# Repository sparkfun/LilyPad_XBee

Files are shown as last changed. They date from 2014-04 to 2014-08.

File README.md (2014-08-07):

LilyPad XBee
============

[LilyPad XBee
*LilyPad XBee (DEV-08937)*](https://www.sparkfun.com/products/8937)

The LilyPad Xbee is a breakout board for the popular XBee modules. 
Board includes easy-to-sew tabs and all the necessary power regulation to run on the LilyPad system. 

Repository Contents
-------------------

* **/Hardware** - All Eagle design files (.brd, .sch, .STL)
* **/Production** - Test bed files and production panel files

License Information
-------------------
The hardware is released under [Creative Commons ShareAlike 4.0 International](https://creativecommons.org/licenses/by-sa/4.0/).

Distributed as-is; no warranty is given.

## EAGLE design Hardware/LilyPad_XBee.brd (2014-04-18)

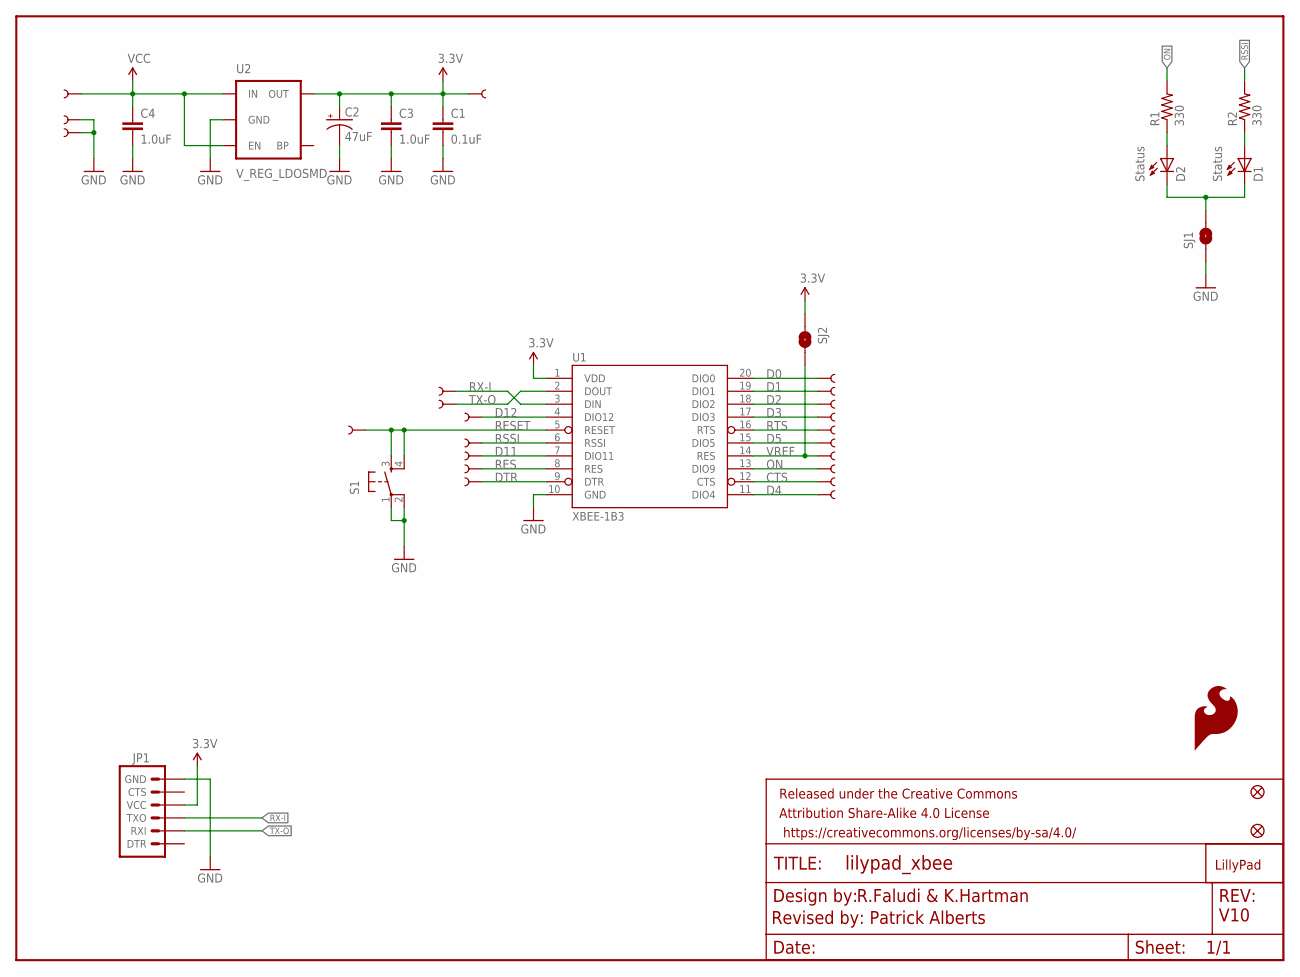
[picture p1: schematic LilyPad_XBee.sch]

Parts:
C1: 0.1uF; 0603-CAP
C2: 47uF; EIA3528
C3, C4: 1.0uF; 0603-CAP
D1, D2: Status; LED-0603
FID1, FID2: FIDUCIAL1X2; FIDUCIAL-1X2
FRAME1: FRAME-LETTER; CREATIVE_COMMONS
GND: SEWTAP9; PETAL-LONG-1-2SIDE
JP1: ARDUINO_SERIAL_PROGRAMPTH; 1X06
LOGO1: SFE_LOGO_FLAME.1COP; SFE_LOGO_FLAME_COPPER_.1
R1, R2: 330; 0603-RES
S1: TAC_SWITCHSMD; TACTILE_SWITCH_SMD
SJ1, SJ2: SOLDERJUMPERNC2; SJ_2S-NOTRACE
U1: XBEE-1B3; XBEE-SMD
U2: V_REG_LDOSMD; SOT23-5
U$1: LOGO-LPLP; LOGO-LILYPAD
U$4, U$30, U$31, U$32, U$33, U$34, U$35, U$36, U$37, U$38, U$39, U$40, U$41, U$42, U$43, U$44, U$45, U$46, U$47, U$48, U$51: SEWTAP9; PETAL-LONG-1-2SIDE

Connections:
3.3V: C1.1, C2.A (+), C3.1, JP1.4 (VCC), SJ2.1, U1.1 (VDD), U2.5 (OUT), U$47.1
CTS: U1.12 (CTS), U$38.1
D0: U1.20 (DIO0), U$34.1
D1: U1.19 (DIO1), U$33.1
D2: U1.18 (DIO2), U$32.1
D3: U1.17 (DIO3), U$31.1
D4: U1.11 (DIO4), U$37.1
D5: U1.15 (DIO5), U$4.1
D11: U1.7 (DIO11), U$42.1
D12: U1.4 (DIO12), U$43.1
DTR: U1.9 (DTR), U$48.1
GND: C1.2, C2.C (-), C3.2, C4.2, JP1.6 (GND), S1.1, S1.2, SJ1.1, U1.10 (GND), U2.2 (GND), U$36.1, U$46.1
unnamed: D1.A, R2.1
unnamed: D2.A, R1.1
unnamed: D1.C, D2.C, SJ1.2
ON: R1.2, U1.13 (DIO9), U$39.1
RES: U1.8 (RES), U$41.1
RESET: GND.1, S1.3, S1.4, U1.5 (RESET)
RSSI: R2.2, U1.6 (RSSI), U$51.1
RTS: U1.16 (RTS), U$30.1
RX-I: JP1.3 (TXO), U1.3 (DIN), U$45.1
TX-O: JP1.2 (RXI), U1.2 (DOUT), U$44.1
VCC: C4.1, U2.1 (IN), U2.3 (EN), U$35.1
VREF: SJ2.2, U1.14 (RES), U$40.1

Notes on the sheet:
R.Faludi & K.Hartman
Revised by: Patrick Alberts
V10

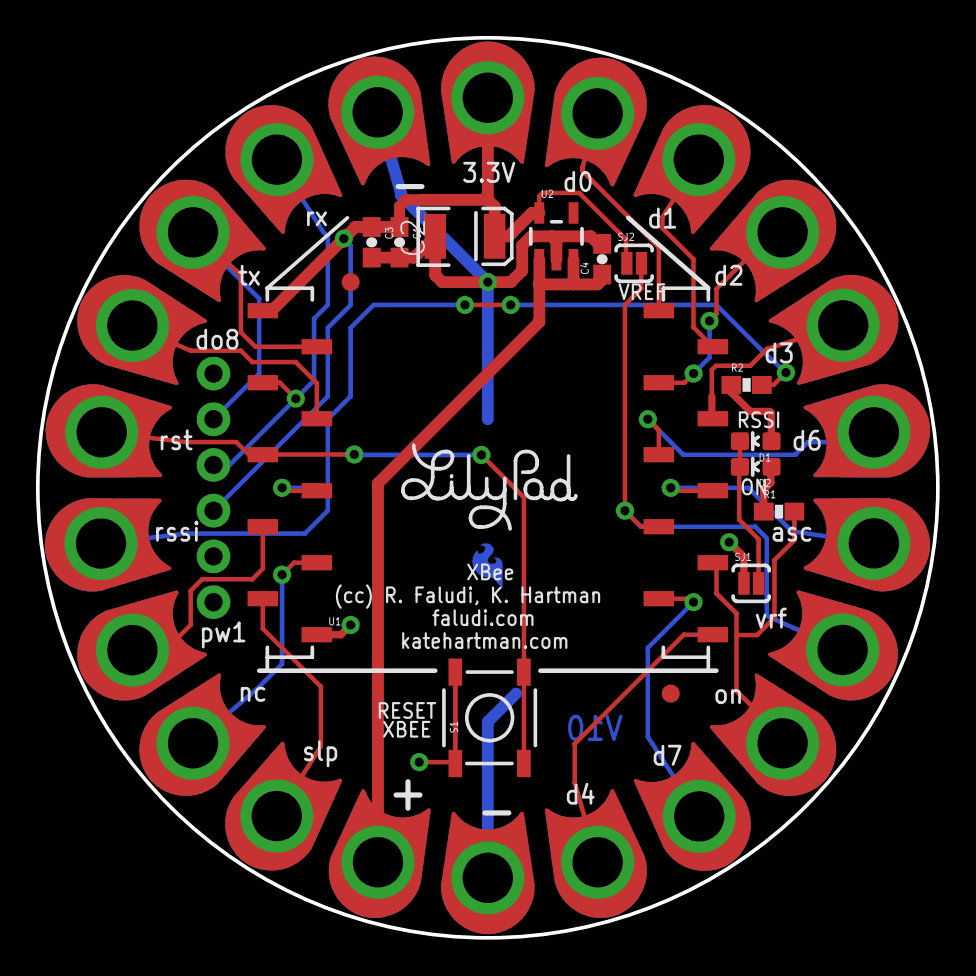
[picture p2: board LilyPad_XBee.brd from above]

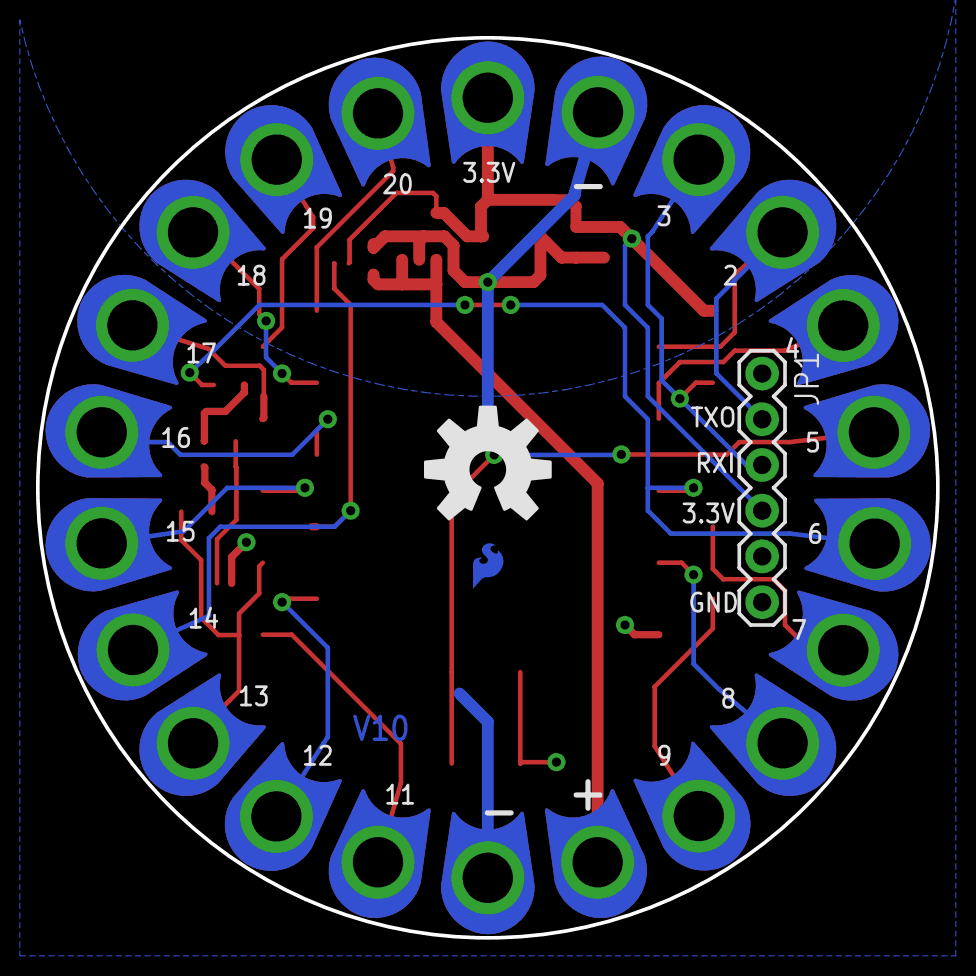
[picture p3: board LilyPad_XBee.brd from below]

Board: 2 copper layers, 50.0 x 50.0 mm, 42 parts (3 on the bottom side), 24 nets.

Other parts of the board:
U$2: OSHW-LOGO-L

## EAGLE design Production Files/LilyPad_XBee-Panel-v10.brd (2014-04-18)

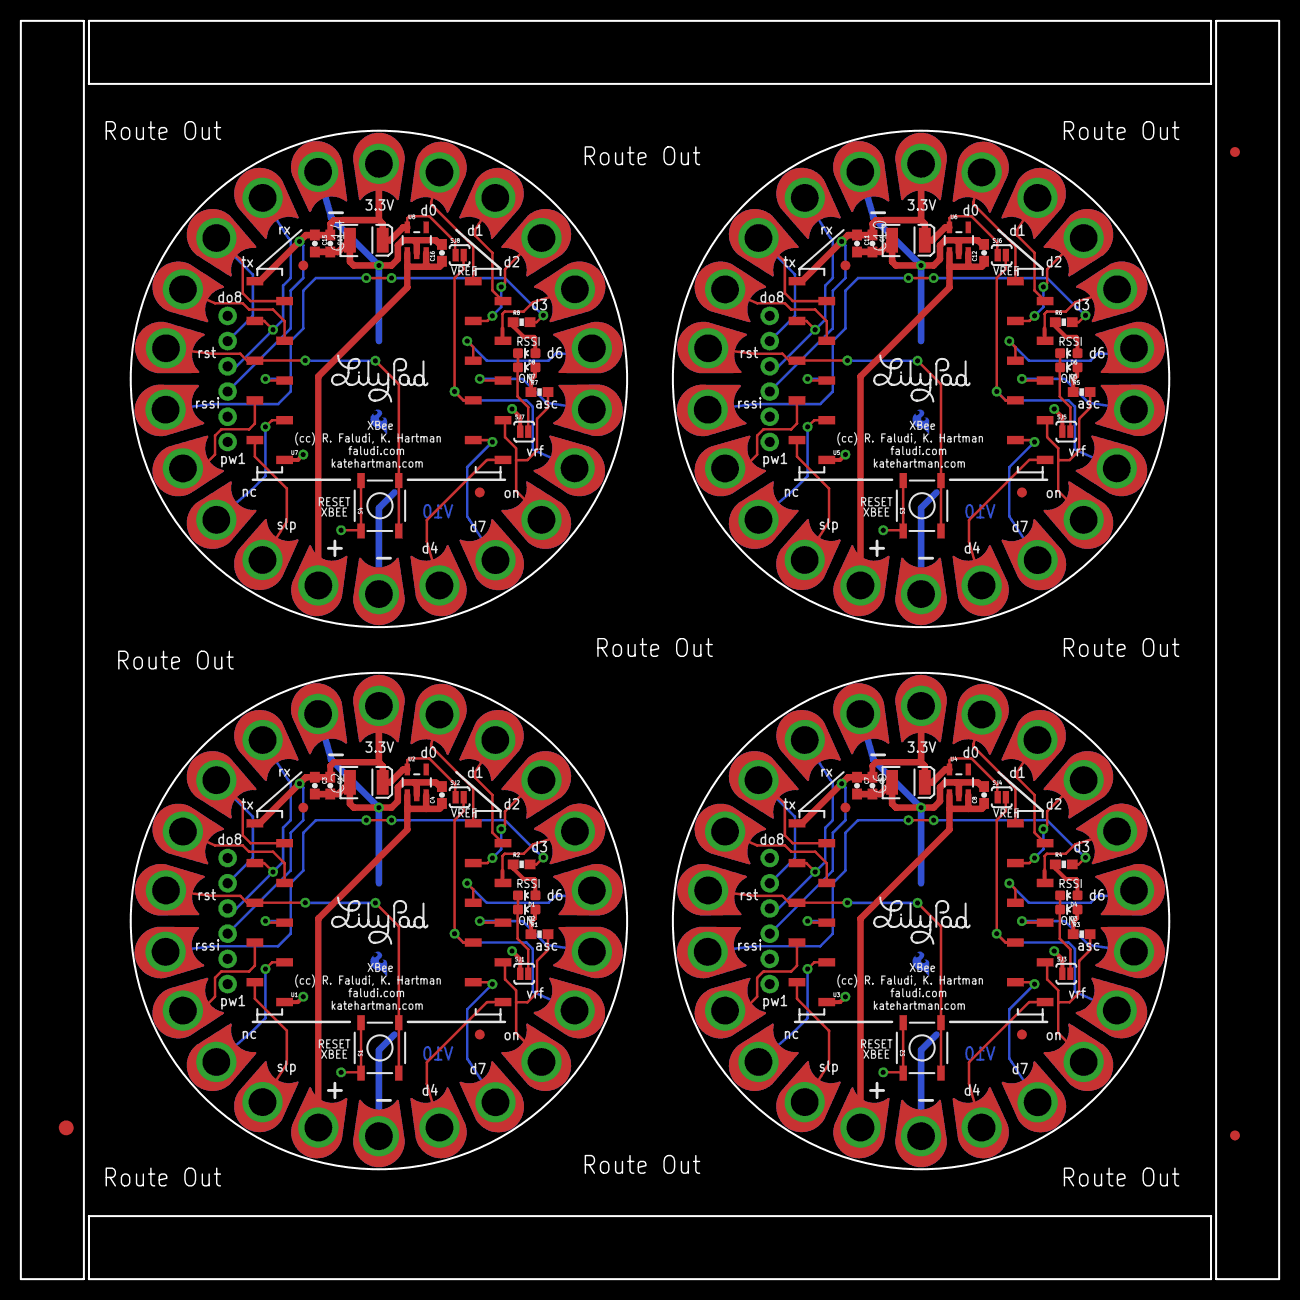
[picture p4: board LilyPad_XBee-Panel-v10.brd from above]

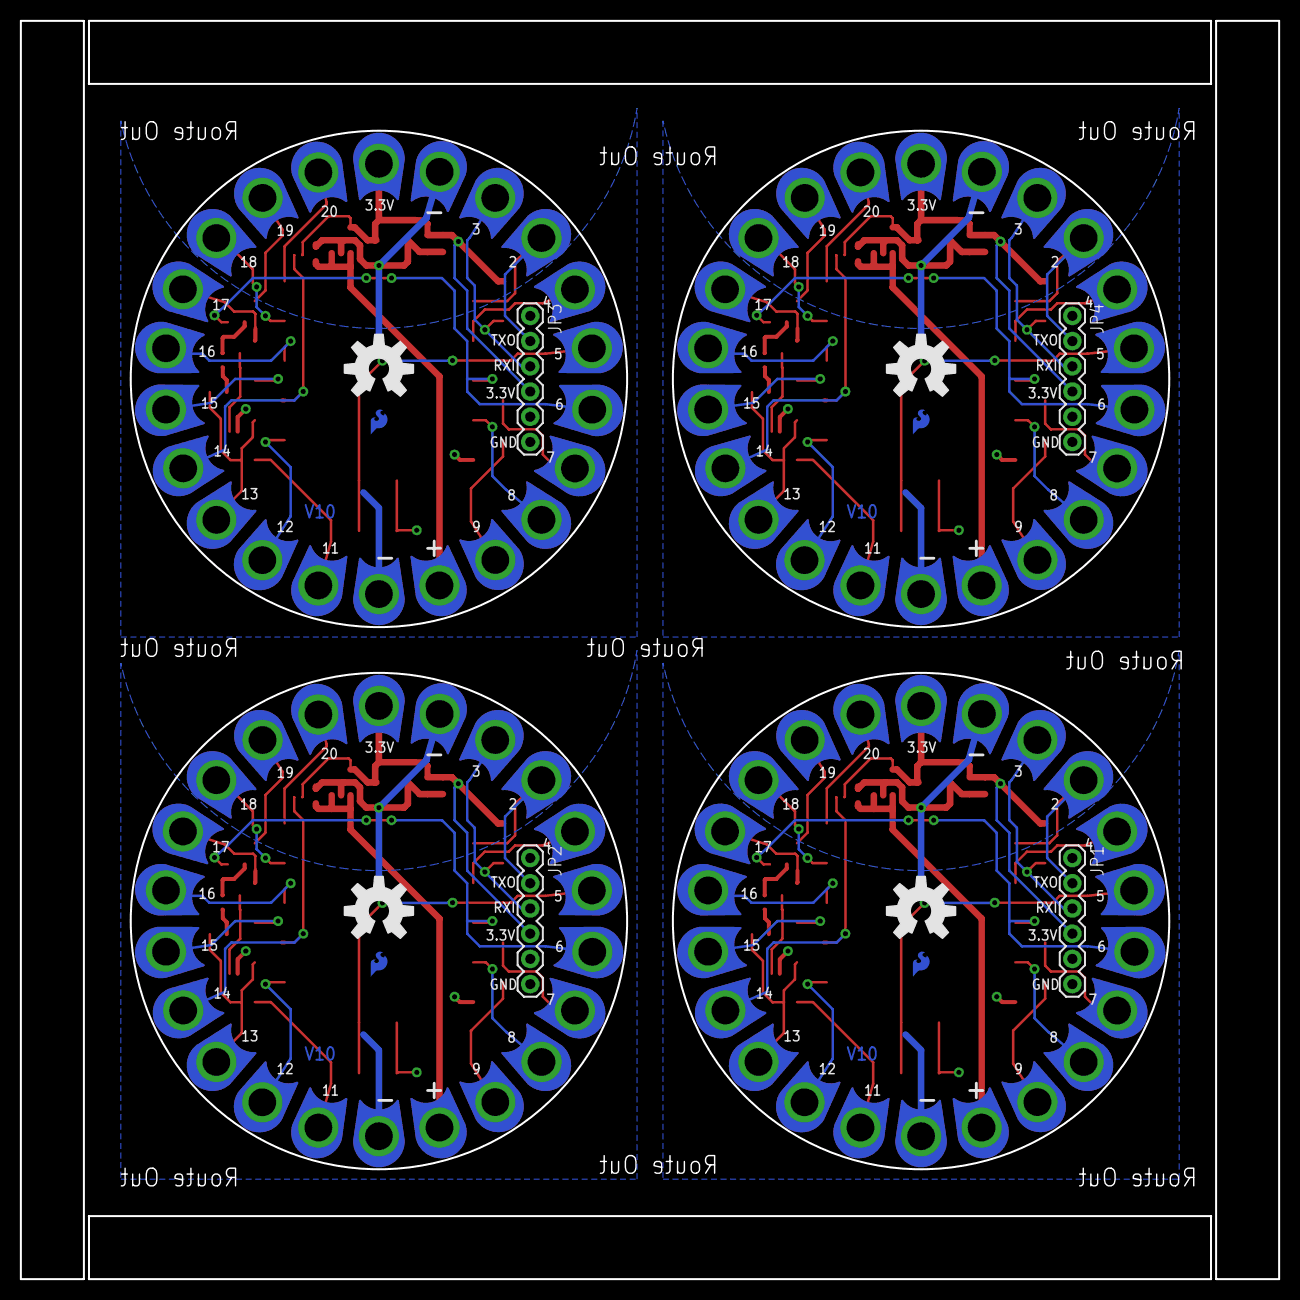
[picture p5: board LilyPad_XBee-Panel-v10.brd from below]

Board: 2 copper layers, 126.7 x 126.7 mm, 167 parts (12 on the bottom side), 96 nets.

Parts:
C1, C5, C9, C13: 0.1uF; 0603-CAP
C2, C6, C10, C14: 47uF; EIA3528
C3, C4, C7, C8, C11, C12, C15, C16: 1.0uF; 0603-CAP
D1, D2, D3, D4, D5, D6, D7, D8: Status; LED-0603
E$1: FIDUCIAL-1.5X3
E$4, E$6: FIDUCIAL-1X2
FID1, FID2, FID3, FID4, FID5, FID6, FID7, FID8: FIDUCIAL1X2; FIDUCIAL-1X2
GND, GND1, GND2, GND3: SEWTAP9; PETAL-LONG-1-2SIDE
JP1, JP2, JP3, JP4: 1X06
LOGO1, LOGO2, LOGO3, LOGO4: SFE_LOGO_FLAME.1COP; SFE_LOGO_FLAME_COPPER_.1
R1, R2, R3, R4, R5, R6, R7, R8: 330; 0603-RES
S1, S2, S3, S4: TACTILE_SWITCH_SMD
SJ1, SJ2, SJ3, SJ4, SJ5, SJ6, SJ7, SJ8: SJ_2S-NOTRACE
U1, U3, U5, U7: XBEE-1B3; XBEE-SMD
U2, U4, U6, U8: V_REG_LDOSMD; SOT23-5
U$1, U$25, U$68, U$91: LOGO-LPLP; LOGO-LILYPAD
U$2, U$26, U$69, U$92: OSHW-LOGO-L
U$3, U$4, U$5, U$6, U$7, U$8, U$9, U$10, U$11, U$12, U$13, U$14, U$15, U$16, U$17, U$18, U$19, U$20, U$21, U$22, U$23, U$24, U$27, U$28, U$29, U$30, U$31, U$32, U$33, U$34, U$35, U$36, U$37, U$38, U$39, U$40, U$41, U$42, U$43, U$44, U$45, U$46, U$47, U$48, U$49, U$50, U$51, U$52, U$53, U$54, U$55, U$56, U$57, U$58, U$59, U$60, U$61, U$62, U$63, U$64, U$65, U$66, U$67, U$70, U$71, U$72, U$73, U$74, U$75, U$76, U$77, U$78, U$79, U$80, U$81, U$82, U$83, U$84, U$85, U$86, U$87, U$88, U$89, U$90: SEWTAP9; PETAL-LONG-1-2SIDE

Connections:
3.3V: C1.1, C2.A, C3.1, JP1.4, SJ2.1, U1.1, U2.5, U$47.1
3.3V1: C5.1, C6.A, C7.1, JP2.4, SJ4.1, U3.1, U4.5, U$21.1
3.3V2: C9.1, C10.A, C11.1, JP3.4, SJ6.1, U5.1, U6.5, U$64.1
3.3V3: C13.1, C14.A, C15.1, JP4.4, SJ8.1, U7.1, U8.5, U$87.1
CTS: U1.12, U$38.1
CTS1: U3.12, U$12.1
CTS2: U5.12, U$55.1
CTS3: U7.12, U$78.1
D0: U1.20, U$34.1
D1: U1.19, U$33.1
D2: U1.18, U$32.1
D3: U1.17, U$31.1
D4: U1.11, U$37.1
D5: U1.15, U$4.1
D6: U3.4, U$17.1
D7: U3.7, U$16.1
D8: U3.11, U$11.1
D9: U3.15, U$24.1
D10: U3.17, U$5.1
D11: U1.7, U$42.1
D12: U1.4, U$43.1
D13: U3.18, U$6.1
D14: U3.19, U$7.1
D15: U3.20, U$8.1
D16: U5.4, U$60.1
D17: U5.7, U$59.1
D18: U5.11, U$54.1
D19: U5.15, U$67.1
D20: U5.17, U$28.1
D21: U5.18, U$29.1
D22: U5.19, U$49.1
D23: U5.20, U$50.1
D24: U7.4, U$83.1
D25: U7.7, U$82.1
D26: U7.11, U$77.1
D27: U7.15, U$90.1
D28: U7.17, U$71.1
D29: U7.18, U$72.1
D30: U7.19, U$73.1
D31: U7.20, U$74.1
DTR: U1.9, U$48.1
DTR1: U3.9, U$22.1
DTR2: U5.9, U$65.1
DTR3: U7.9, U$88.1
GND: C1.2, C2.C, C3.2, C4.2, JP1.6, S1.1, S1.2, SJ1.1, U1.10, U2.2, U$36.1, U$46.1
GND1: C5.2, C6.C, C7.2, C8.2, JP2.6, S2.1, S2.2, SJ3.1, U3.10, U4.2, U$10.1, U$20.1
GND2: C9.2, C10.C, C11.2, C12.2, JP3.6, S3.1, S3.2, SJ5.1, U5.10, U6.2, U$53.1, U$63.1
GND3: C13.2, C14.C, C15.2, C16.2, JP4.6, S4.1, S4.2, SJ7.1, U7.10, U8.2, U$76.1, U$86.1
unnamed: D1.A, R2.1
unnamed: D2.A, R1.1
unnamed: D1.C, D2.C, SJ1.2
unnamed: D3.A, R3.1
unnamed: D4.A, R4.1
unnamed: D3.C, D4.C, SJ3.2
unnamed: D5.A, R5.1
unnamed: D6.A, R6.1
unnamed: D5.C, D6.C, SJ5.2
unnamed: D7.A, R7.1
unnamed: D8.A, R8.1
unnamed: D7.C, D8.C, SJ7.2
ON: R1.2, U1.13, U$39.1
ON1: R3.2, U3.13, U$13.1
ON2: R5.2, U5.13, U$56.1
ON3: R7.2, U7.13, U$79.1
RES: U1.8, U$41.1
RES1: U3.8, U$15.1
RES2: U5.8, U$58.1
RES3: U7.8, U$81.1
RESET: GND.1, S1.3, S1.4, U1.5
RESET1: GND1.1, S2.3, S2.4, U3.5
RESET2: GND2.1, S3.3, S3.4, U5.5
RESET3: GND3.1, S4.3, S4.4, U7.5
RSSI: R2.2, U1.6, U$51.1
RSSI1: R4.2, U3.6, U$23.1
RSSI2: R6.2, U5.6, U$66.1
RSSI3: R8.2, U7.6, U$89.1
RTS: U1.16, U$30.1
RTS1: U3.16, U$3.1
RTS2: U5.16, U$27.1
RTS3: U7.16, U$70.1
RX-I: JP1.3, U1.3, U$45.1
RX-I1: JP2.3, U3.3, U$19.1
RX-I2: JP3.3, U5.3, U$62.1
RX-I3: JP4.3, U7.3, U$85.1
TX-O: JP1.2, U1.2, U$44.1
TX-O1: JP2.2, U3.2, U$18.1
TX-O2: JP3.2, U5.2, U$61.1
TX-O3: JP4.2, U7.2, U$84.1
VCC: C4.1, U2.1, U2.3, U$35.1
VCC1: C8.1, U4.1, U4.3, U$9.1
VCC2: C12.1, U6.1, U6.3, U$52.1
VCC3: C16.1, U8.1, U8.3, U$75.1
VREF: SJ2.2, U1.14, U$40.1
VREF1: SJ4.2, U3.14, U$14.1
VREF2: SJ6.2, U5.14, U$57.1
VREF3: SJ8.2, U7.14, U$80.1

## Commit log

2014-03-18 Initial Commit
    with brd/sch
    [LilyPad_XBee.brd, LilyPad_XBee.sch]
2014-03-19 Reset Switch / Jumper Redo/ 0603
    Added a reset switch, updated the jumpers, oshw logo, and 0603
    [LilyPad_XBee.brd, LilyPad_XBee.sch]
2014-03-24 Added Silk / re arranged LED Resistors
    [LilyPad_XBee.brd, LilyPad_XBee.sch]
2014-03-27 Added Copper Flame/ Silk for jumper
    [LilyPad_XBee.brd, LilyPad_XBee.sch]
2014-04-18 Added fiducials
    [LilyPad_XBee.brd, LilyPad_XBee.sch]
2014-04-18 created panel v10
    [LilyPad_XBee-Panel-v10.brd]
2014-08-07 Adding in current board files
    [LilyPad-XBee-v15.brd, LilyPad-XBee-v15.sch, LilyPad_XBee-Panel-v10.brd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]
2014-08-07 Adding back in revision 1.0 files
    [LilyPad-XBee-v15.brd, LilyPad-XBee-v15.sch, LilyPad_XBee-Panel-v10.brd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]

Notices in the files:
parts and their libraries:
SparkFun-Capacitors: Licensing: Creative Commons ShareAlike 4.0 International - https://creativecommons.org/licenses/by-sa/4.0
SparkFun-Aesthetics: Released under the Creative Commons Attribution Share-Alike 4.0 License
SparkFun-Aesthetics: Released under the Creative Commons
